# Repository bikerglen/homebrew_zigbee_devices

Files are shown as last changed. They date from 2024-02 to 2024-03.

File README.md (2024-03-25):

# homebrew_zigbee_devices

First up: nRF52840-based four-input sleepy end device

Second up: nRF52840-based hall effect contact sensor sleepy end device

1. Install nRF plugins for Visual Studio Code
2. Use the plugin to install version 2.5.1 of the toolchain and sdk
3. Add custom board definition files
4. Add the zigbee_switch_v2 and zigbee_contact_v1 directories as applications.
5. For each application, create a build using the corresponding custom board.
6. Build and flash each application's build.
7. Install four-input.js as a custom handler in zigbee2mqtt.

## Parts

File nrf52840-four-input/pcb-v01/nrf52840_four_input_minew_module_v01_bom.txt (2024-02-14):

C1       Capacitor 0603 0.1uF
C2       Capacitor 1210 100uF
CR2450   TE/Linx BAT-HLD-008-SMT
D1       LED 0805
D7       LED 0805
J1       Samtec FTS-105-01-F-DV-P-TRJ
J2       Phoenix 1725685
R1       Resistor 0603 10k
R2       Resistor 0603 1k
R3       Resistor 0603 1k
SW1      Button KMR211NGLFS
SW2      Button KMR211NGLFS
U1       Wireless Module

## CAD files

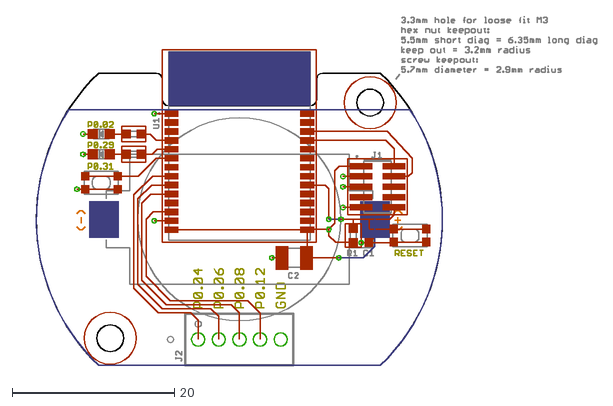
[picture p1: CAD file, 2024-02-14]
nrf52840-four-input/pcb-v01/nrf52840_four_input_minew_module_v01.dxf
71.5 x 43.0

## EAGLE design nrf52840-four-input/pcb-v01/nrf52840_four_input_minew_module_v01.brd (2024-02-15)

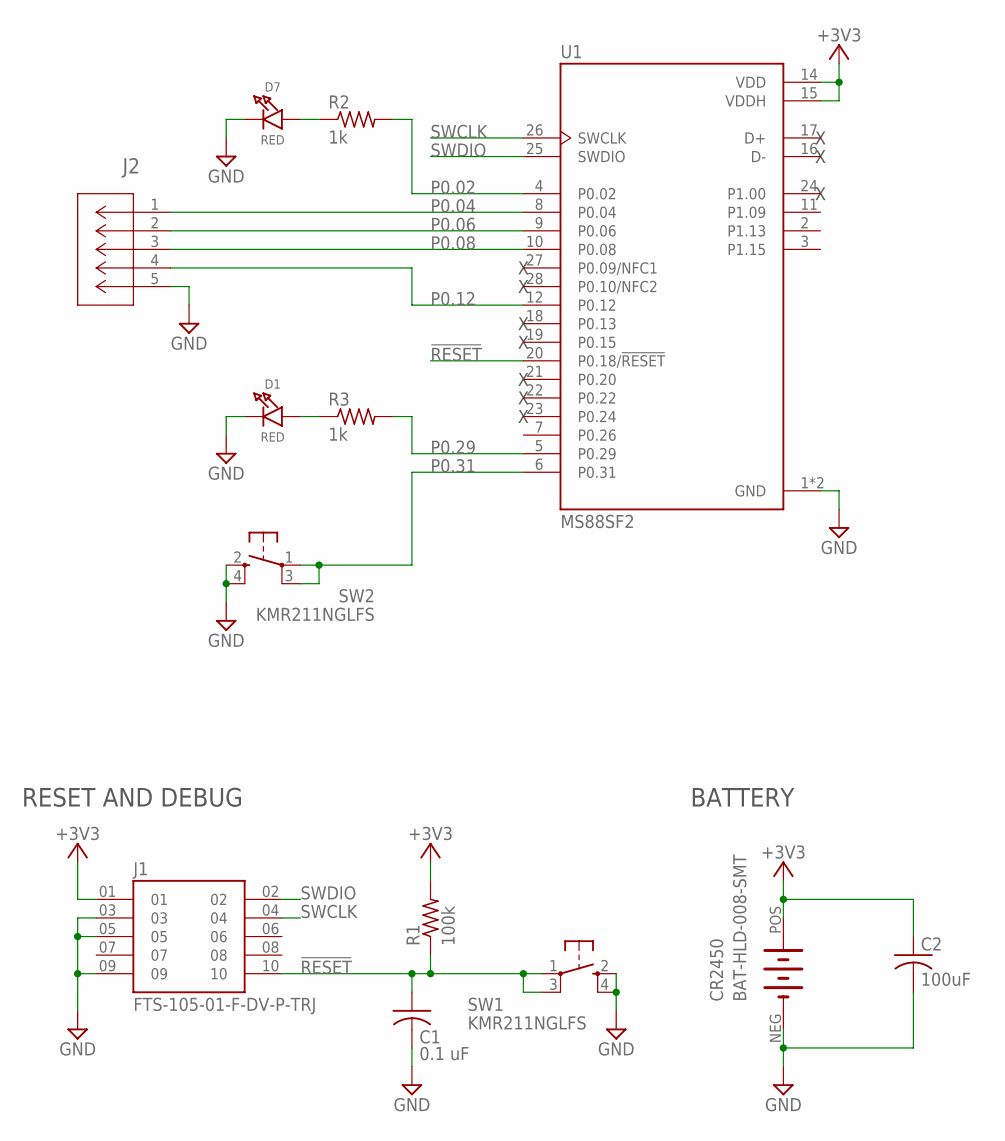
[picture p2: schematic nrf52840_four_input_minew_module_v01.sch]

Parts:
C1: 0.1 uF; C0603K
C2: 100uF; C1210K
CR2450: BAT-HLD-008-SMT
D1, D7: RED; CHIPLED_0805_NOOUTLINE
J1: FTS-105-01-F-DV-P-TRJ; SAMTEC_FTS-105-01-F-DV-P-TR
J2: 1725685; CONN_1725685_PXC
R1: 100k; R0603
R2, R3: 1k; R0603
SW1, SW2: KMR211NGLFS; KMR2
U1: MS88SF2; XCVR_MS88SF2

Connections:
!RESET: C1.1, J1.10, R1.1, SW1.1, SW1.3 (P1), U1.20 (P0.18/!RESET)
+3V3: C2.1, CR2450.POS (+), J1.01, R1.2, U1.14 (VDD), U1.15 (VDDH)
GND: C1.2, C2.2, CR2450.NEG (-), D1.C, D7.C, J1.03, J1.05, J1.09, J2.5, SW1.2 (S), SW1.4 (S1), SW2.2 (S), SW2.4 (S1), U1.1 (GND), U1.13 (GND)
unnamed: D7.A, R2.1
unnamed: D1.A, R3.1
P0.02: R2.2, U1.4 (P0.02)
P0.04: J2.1, U1.8 (P0.04)
P0.06: J2.2, U1.9 (P0.06)
P0.08: J2.3, U1.10 (P0.08)
P0.12: J2.4, U1.12 (P0.12)
P0.29: R3.2, U1.5 (P0.29)
P0.31: SW2.1, SW2.3 (P1), U1.6 (P0.31)
SWCLK: J1.04, U1.26 (SWCLK)
SWDIO: J1.02, U1.25 (SWDIO)

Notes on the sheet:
RESET AND DEBUG
BATTERY

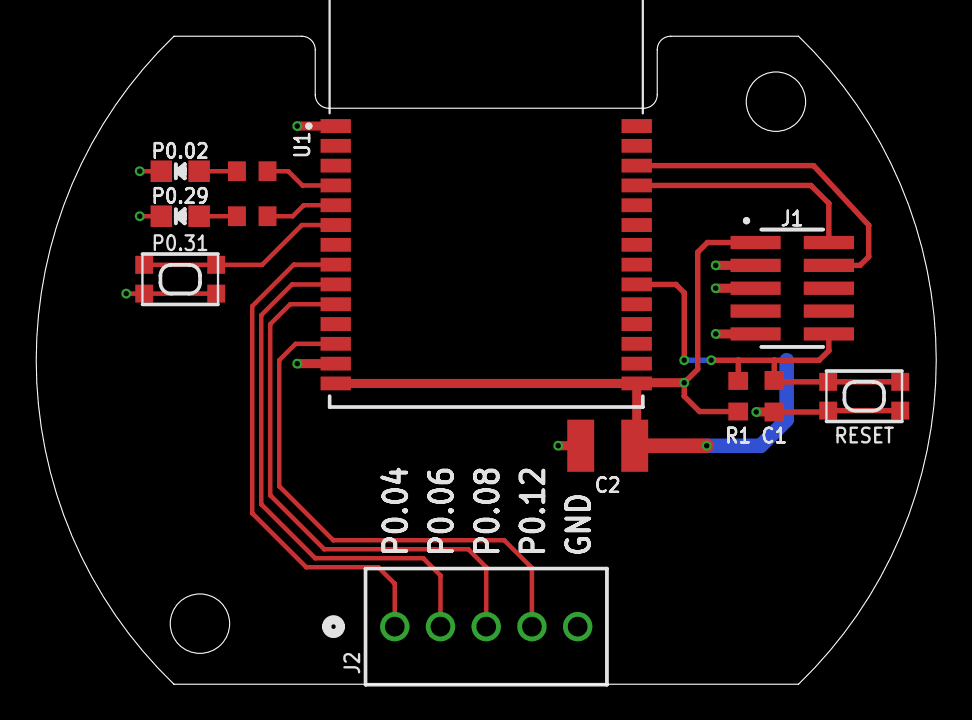
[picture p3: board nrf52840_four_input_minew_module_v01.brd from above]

Board: 2 copper layers, 50.0 x 36.0 mm, 13 parts (1 on the bottom side), 14 nets.

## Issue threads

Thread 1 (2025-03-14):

Power consumption after clic

rdorys, 2025-03-14:
Hi @bikerglen,

First off, thank you for this amazing repository! It has been incredibly helpful in building a Zigbee button based on the nRF52840. Everything is working quite well, but there’s one thing I’m struggling to understand.

I’m using a 52840 DK and measuring around 2.8uA when the system is idle (which is fine, although I’m curious how you’re achieving the 1.8uA consumption).

The issue I’m facing is that after pressing the button, a 3-minute network activity window starts, with a periodic signal every 3 seconds.

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

I’m unable to figure out what’s happening or what the chip is doing during this time. I’ve tried adjusting polling values, disabling turbo poll, and changing the rejoin timeout, but nothing seems to work.

What’s odd is that this behavior doesn’t occur with every button press. If I press the button a bit longer (about 0.3s), there's a high chance that the current drops back down to 2.8uA right after releasing the button.

Do you have any insights on this? Have you observed this behavior in your final product? The only change I made to your code was adjusting the four-button setup to match the DK pinout.

I’m using the nRF SDK 2.8.0.

Thanks again, and looking forward to your thoughts!

Best regards

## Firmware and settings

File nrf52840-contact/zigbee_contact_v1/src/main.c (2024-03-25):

//---------------------------------------------------------------------------------------------
// includes
//

#include <zephyr/kernel.h>
#include <zephyr/device.h>
#include <zephyr/logging/log.h>
#include <zephyr/drivers/gpio.h>
#include <ram_pwrdn.h>

#include <drivers/include/nrfx_saadc.h>

#include <zboss_api.h>
#include <zboss_api_addons.h>
#include <zb_zcl_reporting.h>
#include <zigbee/zigbee_app_utils.h>
#include <zigbee/zigbee_error_handler.h>
#include <zb_nrf_platform.h>
#include "zb_mem_config_custom.h"
#include "zb_four_input.h"

#include "leds.h"
#include "buttons.h"


//---------------------------------------------------------------------------------------------
// defines
//

// Basic cluster attributes initial values. For more information, see section 3.2.2.2 of the ZCL specification.
#define FOUR_INPUT_INIT_BASIC_APP_VERSION       01                                  // Version of the application software (1 byte).
#define FOUR_INPUT_INIT_BASIC_STACK_VERSION     10                                  // Version of the implementation of the Zigbee stack (1 byte).
#define FOUR_INPUT_INIT_BASIC_HW_VERSION        11                                  // Version of the hardware of the device (1 byte).
#define FOUR_INPUT_INIT_BASIC_MANUF_NAME        "bikerglen.com"                     // Manufacturer name (32 bytes).
#define FOUR_INPUT_INIT_BASIC_MODEL_ID          "four-input"                        // Model number assigned by the manufacturer (32-bytes long string).
#define FOUR_INPUT_INIT_BASIC_DATE_CODE         "20240226"                          // Date provided by the manufacturer of the device in ISO 8601 format (YYYYMMDD), for the first 8 bytes. The remaining 8 bytes are manufacturer-specific.
#define FOUR_INPUT_INIT_BASIC_POWER_SOURCE      ZB_ZCL_BASIC_POWER_SOURCE_BATTERY   // Type of power source or sources available for the device. For possible values, see section 3.2.2.2.8 of the ZCL specification.
#define FOUR_INPUT_INIT_BASIC_LOCATION_DESC     "Earth"                             // Description of the physical location of the device (16 bytes). You can modify it during the commisioning process.
#define FOUR_INPUT_INIT_BASIC_PH_ENV            ZB_ZCL_BASIC_ENV_UNSPECIFIED        // Description of the type of physical environment. For possible values, see section 3.2.2.2.10 of the ZCL specification.

// source endpoint for our device
#define SOURCE_ENDPOINT            1

// destination short address and endpoint (always endpoint 1 on the coordinator)
#define DEST_SHORT_ADDR            0x0000
#define DEST_ENDPOINT              1

// Do not erase NVRAM to save the network parameters after device reboot or
// power-off. NOTE: If this option is set to ZB_TRUE then do full device erase
// for all network devices before running other samples.
#define ERASE_PERSISTENT_CONFIG    ZB_FALSE

// LEDs
#define ZIGBEE_NETWORK_STATE_LED   0      // on: disconnected, blinking: identify, off: normal operation
#define USER_LED                   1      // unused

// Buttons
#define BUTTON_0                   BIT(0) // send zcl off/on/toggle/custom commands
#define BUTTON_1                   BIT(1) // short press: identify, long press: factory reset

// no idea but required for successful compile
#define bat_num

// read and report battery voltage after an initial delay after joining the network 
// then read and report battery voltage after the specified period elapses.
#define READ_BATTERY_VOLTAGE_INITIAL_DELAY K_SECONDS(10)
#define READ_BATTERY_VOLTAGE_TIMER_PERIOD  K_HOURS(8)


//---------------------------------------------------------------------------------------------
// typedefs
//

// attribute storage for battery power config
struct zb_zcl_power_attrs {
    zb_uint8_t voltage; // Attribute 3.3.2.2.3.1
    zb_uint8_t size; // Attribute 3.3.2.2.4.2
    zb_uint8_t quantity; // Attribute 3.3.2.2.4.4
    zb_uint8_t rated_voltage; // Attribute 3.3.2.2.4.5
    zb_uint8_t alarm_mask; // Attribute 3.3.2.2.4.6
    zb_uint8_t voltage_min_threshold; // Attribute 3.3.2.2.4.7
    zb_uint8_t percent_remaining; // Attribute 3.3.2.2.3.1
    zb_uint8_t voltage_threshold_1; // Attribute 3.3.2.2.4.8
    zb_uint8_t voltage_threshold_2; // Attribute 3.3.2.2.4.8
    zb_uint8_t voltage_threshold_3; // Attribute 3.3.2.2.4.8
    zb_uint8_t percent_min_threshold; // Attribute 3.3.2.2.4.9
    zb_uint8_t percent_threshold_1; // Attribute 3.3.2.2.4.10
    zb_uint8_t percent_threshold_2; // Attribute 3.3.2.2.4.10
    zb_uint8_t percent_threshold_3; // Attribute 3.3.2.2.4.10
    zb_uint32_t alarm_state; // Attribute 3.3.2.2.4.11
};

typedef struct zb_zcl_power_attrs zb_zcl_power_attrs_t;

// attribute storage for our device
struct zb_device_ctx {
	zb_zcl_basic_attrs_ext_t basic_attr;
	zb_zcl_identify_attrs_t identify_attr;
	zb_zcl_power_attrs_t power_attr;
};

// storage for the destination short address and endpoint number
struct dest_context {
	zb_uint8_t endpoint;
	zb_uint16_t short_addr;
};

// coin cell voltage-capacity pairs
typedef struct {
  uint16_t      voltage;
  uint8_t       capacity;
} voltage_capacity_pair_t;


//---------------------------------------------------------------------------------------------
// Prototypes
//

// used to display reporting info structures if needed
zb_zcl_reporting_info_t *zb_zcl_get_reporting_info(zb_uint8_t slot_number);

void zboss_signal_handler (zb_bufid_t bufid);
static void configure_gpio (void);
static void button_handler (uint32_t button_state, uint32_t has_changed);
static void light_switch_send_on_off (zb_bufid_t bufid, zb_uint16_t cmd_id);
static void start_identifying (zb_bufid_t bufid);
static void identify_cb (zb_bufid_t bufid);
static void toggle_identify_led (zb_bufid_t bufid);
static void app_clusters_attr_init (void);
static void configure_attribute_reporting (void);
static void read_battery_voltage_cb (struct k_timer *timer);
static void read_battery_voltage_work_handler(struct k_work *work);
static uint8_t cr2032_CalculateLevel (uint16_t voltage);
static void send_attribute_report (zb_bufid_t bufid, zb_uint16_t cmd_id);

#if DT_NODE_EXISTS(DT_NODELABEL(sw_spi_cs_n))
static void power_down_spi_flash (void);
#endif


//---------------------------------------------------------------------------------------------
// Globals
//

#if !defined ZB_ED_ROLE
#error Define ZB_ED_ROLE to compile light switch (End Device) source code.
#endif

LOG_MODULE_REGISTER (app, LOG_LEVEL_INF);

// attribute storage for our device
static struct zb_device_ctx dev_ctx;

// storage for the destination short address and endpoint number
static struct dest_context dest_ctx;

// Declare attribute list for Basic cluster (server).
ZB_ZCL_DECLARE_BASIC_ATTRIB_LIST_EXT
(
	basic_server_attr_list,
	&dev_ctx.basic_attr.zcl_version,
	&dev_ctx.basic_attr.app_version,
	&dev_ctx.basic_attr.stack_version,
	&dev_ctx.basic_attr.hw_version,
	dev_ctx.basic_attr.mf_name,
	dev_ctx.basic_attr.model_id,
	dev_ctx.basic_attr.date_code,
	&dev_ctx.basic_attr.power_source,
	dev_ctx.basic_attr.location_id,
	&dev_ctx.basic_attr.ph_env,
	dev_ctx.basic_attr.sw_ver
);

// Declare attribute list for Identify cluster (client).
ZB_ZCL_DECLARE_IDENTIFY_CLIENT_ATTRIB_LIST
(
	identify_client_attr_list
);

// Declare attribute list for Identify cluster (server).
ZB_ZCL_DECLARE_IDENTIFY_SERVER_ATTRIB_LIST
(
	identify_server_attr_list,
	&dev_ctx.identify_attr.identify_time
);

// Declare attribute list for On/Off cluster (client).
ZB_ZCL_DECLARE_ON_OFF_CLIENT_ATTRIB_LIST
(
	on_off_client_attr_list
);

// Declare attribute list for power configuration cluster (server).
ZB_ZCL_DECLARE_POWER_CONFIG_BATTERY_ATTRIB_LIST_EXT(
	power_config_server_attr_list,
	&dev_ctx.power_attr.voltage,
	&dev_ctx.power_attr.size,
	&dev_ctx.power_attr.quantity,
	&dev_ctx.power_attr.rated_voltage,
	&dev_ctx.power_attr.alarm_mask,
	&dev_ctx.power_attr.voltage_min_threshold,
	&dev_ctx.power_attr.percent_remaining,
	&dev_ctx.power_attr.voltage_threshold_1,
	&dev_ctx.power_attr.voltage_threshold_2,
	&dev_ctx.power_attr.voltage_threshold_3,
	&dev_ctx.power_attr.percent_min_threshold,
	&dev_ctx.power_attr.percent_threshold_1,
	&dev_ctx.power_attr.percent_threshold_2,
	&dev_ctx.power_attr.percent_threshold_3,
	&dev_ctx.power_attr.alarm_state
);

// Declare cluster list for four input device.
ZB_DECLARE_FOUR_INPUT_CLUSTER_LIST
(
	four_input_clusters,
	basic_server_attr_list,
	identify_client_attr_list,
	identify_server_attr_list,
	on_off_client_attr_list,
	power_config_server_attr_list
);

// Declare endpoint for four input device.
ZB_DECLARE_FOUR_INPUT_EP
(
	four_input_ep,
	SOURCE_ENDPOINT,
	four_input_clusters
);

// Declare application's device context (list of registered endpoints) for four input device.
ZBOSS_DECLARE_DEVICE_CTX_1_EP
(
	four_input_ctx, 
	four_input_ep
);

// alarm for taking an ADC reading every 6 hours
struct k_timer read_battery_voltage_timer;
K_WORK_DEFINE (read_battery_voltage_work, read_battery_voltage_work_handler);

// Voltage - Capacity pair table from thunderboard react
// Algorithm assumes the values are arranged in a descending order.
// The values in the table are an average of those found in the CR2032 datasheets from
// Energizer, Maxell and Panasonic. Table modified for zigbee half percent steps.
static voltage_capacity_pair_t vcPairs[] =
{ { 3000, 200 }, { 2900, 160 }, { 2800, 120 }, { 2700, 80 }, { 2600, 60 },
  { 2500, 40 }, { 2400, 20 }, { 2000, 0 } };


//---------------------------------------------------------------------------------------------
// main
//

int main (void)
{
	LOG_INF ("Starting Four Input Device");

	// initialize
	configure_gpio ();
	register_factory_reset_button (BUTTON_1);
	zigbee_erase_persistent_storage (ERASE_PERSISTENT_CONFIG);
	zb_set_ed_timeout (ED_AGING_TIMEOUT_64MIN);
    zb_set_keepalive_timeout (ZB_MILLISECONDS_TO_BEACON_INTERVAL(3600*1000));
    
#if DT_NODE_EXISTS (DT_NODELABEL (sw_spi_cs_n))
	// place spi flash in power down mode
	power_down_spi_flash ();
#endif

	// send things to endpoint 1 on the coordinator
	dest_ctx.short_addr = DEST_SHORT_ADDR;
	dest_ctx.endpoint = DEST_ENDPOINT;

	// configure for lowest power
	zigbee_configure_sleepy_behavior (true);
	power_down_unused_ram ();

	// register switch device context (endpoints)
	ZB_AF_REGISTER_DEVICE_CTX (&four_input_ctx);

	// initialize application clusters
	app_clusters_attr_init ();

	// register handlers to identify notifications
	ZB_AF_SET_IDENTIFY_NOTIFICATION_HANDLER(SOURCE_ENDPOINT, identify_cb);

	// initialize read battery voltage timer
	k_timer_init (&read_battery_voltage_timer, read_battery_voltage_cb, NULL);

	// start Zigbee default thread
	zigbee_enable ();

	LOG_INF ("Four Input Device started");

	// suspend main thread
	while (1) {
		k_sleep (K_FOREVER);
	}
}


//---------------------------------------------------------------------------------------------
// zigbee stack event handler
//

void zboss_signal_handler(zb_bufid_t bufid)
{
	static bool lastJoin = false;

	zb_zdo_app_signal_hdr_t *sig_hndler = NULL;
	zb_zdo_app_signal_type_t sig = zb_get_app_signal(bufid, &sig_hndler);
	zb_ret_t status = ZB_GET_APP_SIGNAL_STATUS(bufid);

	// Update network status LED.
	// zigbee_led_status_update(bufid, ZIGBEE_NETWORK_STATE_LED);

	// Call default signal handler until there's a reason to check for different signals
	// the default handler evens calls zb_sleep_now for us
	ZB_ERROR_CHECK(zigbee_default_signal_handler(bufid));

	// free buffer if it's allocated
	if (bufid) {
		zb_buf_free(bufid);
	}

	// once joined, set the poll and battery voltage intervals to an hour.
	// if using a sparkfun board with a spi flash chip, drop the flash chip 
	// into power down mode again just in case missed it the first time.
	bool thisJoin = ZB_JOINED();
	if ((lastJoin == false) && (thisJoin == true)) {
		LOG_INF ("joined network!");
		led_set_off (ZIGBEE_NETWORK_STATE_LED);
		zb_zdo_pim_set_long_poll_interval (3600*1000);
		configure_attribute_reporting ();
		status = zb_zcl_start_attr_reporting(SOURCE_ENDPOINT, ZB_ZCL_CLUSTER_ID_POWER_CONFIG, ZB_ZCL_CLUSTER_SERVER_ROLE, ZB_ZCL_ATTR_POWER_CONFIG_BATTERY_VOLTAGE_ID);
		k_timer_start(&read_battery_voltage_timer, READ_BATTERY_VOLTAGE_INITIAL_DELAY, READ_BATTERY_VOLTAGE_TIMER_PERIOD);
#if DT_NODE_EXISTS(DT_NODELABEL(sw_spi_cs_n))
		power_down_spi_flash ();
#endif
	} else if ((lastJoin == true) && (thisJoin == false)) {
		LOG_INF ("left network!");
		// no longer joined, turn on network state led and stop reading battery voltage
		led_set_on (ZIGBEE_NETWORK_STATE_LED);
		k_timer_stop(&read_battery_voltage_timer);
	}
	lastJoin = thisJoin;
}


//---------------------------------------------------------------------------------------------
// configure attribute reporting
//

#define RPT_MIN 0x0001
#define RPT_MAX 0xFFFE

static void configure_attribute_reporting (void)
{
	// If the maximum reporting interval is set to 0xffff then the device shall not issue any 
	// reports for the attribute. If it is set to 0x0000 and minimum reporting interval is set 
	// to something other than 0xffff then the device shall not do periodic reporting.
	// It can still send reports on value change in the last case, but not periodic.

	zb_zcl_reporting_info_t batt_rep_info;
	zb_ret_t status;

	memset(&batt_rep_info, 0, sizeof(batt_rep_info));
	batt_rep_info.direction = ZB_ZCL_CONFIGURE_REPORTING_SEND_REPORT;
	batt_rep_info.ep = SOURCE_ENDPOINT;
	batt_rep_info.cluster_id = ZB_ZCL_CLUSTER_ID_POWER_CONFIG;
	batt_rep_info.cluster_role = ZB_ZCL_CLUSTER_SERVER_ROLE;
	batt_rep_info.attr_id = ZB_ZCL_ATTR_POWER_CONFIG_BATTERY_VOLTAGE_ID;
	batt_rep_info.dst.short_addr = 0x0000;
	batt_rep_info.dst.endpoint = 1;
	batt_rep_info.dst.profile_id = ZB_AF_HA_PROFILE_ID;
	batt_rep_info.u.send_info.min_interval = RPT_MIN;
	batt_rep_info.u.send_info.max_interval = 0;
	batt_rep_info.u.send_info.delta.u8 = 0x00;
	batt_rep_info.u.send_info.reported_value.u8 = 0;
	batt_rep_info.u.send_info.def_min_interval = RPT_MIN;
	batt_rep_info.u.send_info.def_max_interval = RPT_MAX;
	status = zb_zcl_put_reporting_info(&batt_rep_info, ZB_TRUE);       

	memset(&batt_rep_info, 0, sizeof(batt_rep_info));
	batt_rep_info.direction = ZB_ZCL_CONFIGURE_REPORTING_SEND_REPORT;
	batt_rep_info.ep = SOURCE_ENDPOINT;
	batt_rep_info.cluster_id = ZB_ZCL_CLUSTER_ID_POWER_CONFIG;
	batt_rep_info.cluster_role = ZB_ZCL_CLUSTER_SERVER_ROLE;
	batt_rep_info.attr_id = ZB_ZCL_ATTR_POWER_CONFIG_BATTERY_PERCENTAGE_REMAINING_ID;
	batt_rep_info.dst.short_addr = 0x0000;
	batt_rep_info.dst.endpoint = 1;
	batt_rep_info.dst.profile_id = ZB_AF_HA_PROFILE_ID;
	batt_rep_info.u.send_info.min_interval = RPT_MIN;
	batt_rep_info.u.send_info.max_interval = RPT_MAX;
	batt_rep_info.u.send_info.delta.u8 = 0x00;
	batt_rep_info.u.send_info.reported_value.u8 = 0;
	batt_rep_info.u.send_info.def_min_interval = RPT_MIN;
	batt_rep_info.u.send_info.def_max_interval = RPT_MAX;
	status = zb_zcl_put_reporting_info(&batt_rep_info, ZB_TRUE);       

	memset(&batt_rep_info, 0, sizeof(batt_rep_info));
	batt_rep_info.direction = ZB_ZCL_CONFIGURE_REPORTING_SEND_REPORT;
	batt_rep_info.ep = SOURCE_ENDPOINT;
	batt_rep_info.cluster_id = ZB_ZCL_CLUSTER_ID_POWER_CONFIG;
	batt_rep_info.cluster_role = ZB_ZCL_CLUSTER_SERVER_ROLE;
	batt_rep_info.attr_id = ZB_ZCL_ATTR_POWER_CONFIG_BATTERY_ALARM_STATE_ID;
	batt_rep_info.dst.short_addr = 0x0000;
	batt_rep_info.dst.endpoint = 1;
	batt_rep_info.dst.profile_id = ZB_AF_HA_PROFILE_ID;
	batt_rep_info.u.send_info.min_interval = RPT_MIN;
	batt_rep_info.u.send_info.max_interval = RPT_MAX;
	batt_rep_info.u.send_info.delta.u8 = 0x00;
	batt_rep_info.u.send_info.reported_value.u32 = 0;
	batt_rep_info.u.send_info.def_min_interval = RPT_MIN;
	batt_rep_info.u.send_info.def_max_interval = RPT_MAX;
	status = zb_zcl_put_reporting_info(&batt_rep_info, ZB_TRUE);       
}


//---------------------------------------------------------------------------------------------
// configure LEDs and buttons
//

static void configure_gpio (void)
{
	int err;

	led_init ();

#if DT_NODE_EXISTS(DT_NODELABEL(led0))
	// turn led on until network is joined
	led_set_on (ZIGBEE_NETWORK_STATE_LED); 
#endif

#if DT_NODE_EXISTS(DT_NODELABEL(led1))
	// turn unused user LED off
	led_set_off (USER_LED); 
#endif

	buttons_init (button_handler);
}


//---------------------------------------------------------------------------------------------
// set default values of attributes in the application's clusters
//

static void app_clusters_attr_init (void)
{
	// Basic cluster attributes data.
	dev_ctx.basic_attr.zcl_version   = ZB_ZCL_VERSION;
	dev_ctx.basic_attr.power_source  = ZB_ZCL_BASIC_POWER_SOURCE_UNKNOWN;
    dev_ctx.basic_attr.power_source  = FOUR_INPUT_INIT_BASIC_POWER_SOURCE;
    dev_ctx.basic_attr.stack_version = FOUR_INPUT_INIT_BASIC_STACK_VERSION;
    dev_ctx.basic_attr.hw_version    = FOUR_INPUT_INIT_BASIC_HW_VERSION;

    // Use ZB_ZCL_SET_STRING_VAL to set strings, because the first byte should
    // contain string length without trailing zero.
    //
    // For example "test" string wil be encoded as:
    //   [(0x4), 't', 'e', 's', 't']

    ZB_ZCL_SET_STRING_VAL(dev_ctx.basic_attr.mf_name,
                          FOUR_INPUT_INIT_BASIC_MANUF_NAME,
                          ZB_ZCL_STRING_CONST_SIZE(FOUR_INPUT_INIT_BASIC_MANUF_NAME));

    ZB_ZCL_SET_STRING_VAL(dev_ctx.basic_attr.model_id,
                          FOUR_INPUT_INIT_BASIC_MODEL_ID,
                          ZB_ZCL_STRING_CONST_SIZE(FOUR_INPUT_INIT_BASIC_MODEL_ID));

    ZB_ZCL_SET_STRING_VAL(dev_ctx.basic_attr.date_code,
                          FOUR_INPUT_INIT_BASIC_DATE_CODE,
                          ZB_ZCL_STRING_CONST_SIZE(FOUR_INPUT_INIT_BASIC_DATE_CODE));


    ZB_ZCL_SET_STRING_VAL(dev_ctx.basic_attr.location_id,
                          FOUR_INPUT_INIT_BASIC_LOCATION_DESC,
                          ZB_ZCL_STRING_CONST_SIZE(FOUR_INPUT_INIT_BASIC_LOCATION_DESC));


    dev_ctx.basic_attr.ph_env = FOUR_INPUT_INIT_BASIC_PH_ENV;

	// Identify cluster attributes data.
	dev_ctx.identify_attr.identify_time = ZB_ZCL_IDENTIFY_IDENTIFY_TIME_DEFAULT_VALUE;

	// Power config attributes data.
	dev_ctx.power_attr.voltage               = ZB_ZCL_POWER_CONFIG_BATTERY_VOLTAGE_INVALID;
	dev_ctx.power_attr.size                  = ZB_ZCL_POWER_CONFIG_BATTERY_SIZE_OTHER;
	dev_ctx.power_attr.quantity              = 1;
	dev_ctx.power_attr.rated_voltage         = 30;
	dev_ctx.power_attr.alarm_mask            = 0x00;
	dev_ctx.power_attr.voltage_min_threshold = 20;
	dev_ctx.power_attr.percent_remaining     = ZB_ZCL_POWER_CONFIG_BATTERY_REMAINING_UNKNOWN;
	dev_ctx.power_attr.voltage_threshold_1   = 22;
	dev_ctx.power_attr.voltage_threshold_2   = 24;
	dev_ctx.power_attr.voltage_threshold_3   = 26;
	dev_ctx.power_attr.percent_min_threshold = 2*10;
	dev_ctx.power_attr.percent_threshold_1   = 2*15;
	dev_ctx.power_attr.percent_threshold_2   = 2*20;
	dev_ctx.power_attr.percent_threshold_3   = 2*25;
	dev_ctx.power_attr.alarm_state           = 0x00000000;
}


//---------------------------------------------------------------------------------------------
// button event handler
//

static void button_handler (uint32_t button_state, uint32_t has_changed)
{
	zb_uint16_t cmd_id = 0xFFFF;
	zb_ret_t zb_err_code;

	LOG_INF ("button_handler");

	// inform default signal handler about user input at the device
	user_input_indicate ();

    // check for start of factory reset
	check_factory_reset_button (button_state, has_changed);

	// check for button presses and releases
	if (BUTTON_0 & has_changed & button_state) {			// magnet away from sensor => high => on
		cmd_id = ZB_ZCL_CMD_ON_OFF_ON_ID;
	} else if (BUTTON_0 & has_changed & ~button_state) {	// magnet near sensor => low => off
		cmd_id = ZB_ZCL_CMD_ON_OFF_OFF_ID;
	} else if (BUTTON_1 & has_changed & ~button_state) {	// button 1 released
		// button 1 released: if not factory reset, enter identify mode
		if (!was_factory_reset_done ()) {
			// Button released before Factory Reset, Start identification mode
			ZB_SCHEDULE_APP_CALLBACK (start_identifying, 0);
		}
	}

	// if needed, send a command
	if (cmd_id != 0xFFFF) {
		zb_err_code = zb_buf_get_out_delayed_ext (light_switch_send_on_off, cmd_id, 0);
		ZB_ERROR_CHECK (zb_err_code);
	}

	// led_set_on (USER_LED); 
	// led_set_off (USER_LED); 
}


//---------------------------------------------------------------------------------------------
// send light switch on off command
//
// bufid    Non-zero reference to Zigbee stack buffer that will be used to construct on/off request.
// cmd_id   ZCL command id.
//

static void light_switch_send_on_off (zb_bufid_t bufid, zb_uint16_t cmd_id)
{
	LOG_INF("Send ON/OFF command: %d", cmd_id);

	ZB_ZCL_ON_OFF_SEND_REQ(bufid,
			       dest_ctx.short_addr,
			       ZB_APS_ADDR_MODE_16_ENDP_PRESENT,
			       dest_ctx.endpoint,
			       SOURCE_ENDPOINT,
			       ZB_AF_HA_PROFILE_ID,
			       ZB_ZCL_DISABLE_DEFAULT_RESPONSE,
			       cmd_id,
			       NULL);
}


//---------------------------------------------------------------------------------------------
// start identifying
//

static void start_identifying (zb_bufid_t bufid)
{
	ZVUNUSED(bufid);

	if (ZB_JOINED()) {
		// Check if endpoint is in identifying mode,
		// if not, put desired endpoint in identifying mode.
		if (dev_ctx.identify_attr.identify_time ==
		    ZB_ZCL_IDENTIFY_IDENTIFY_TIME_DEFAULT_VALUE) {

			zb_ret_t zb_err_code = zb_bdb_finding_binding_target(SOURCE_ENDPOINT);

			if (zb_err_code == RET_OK) {
				LOG_INF("Enter identify mode");
			} else if (zb_err_code == RET_INVALID_STATE) {
				LOG_WRN("RET_INVALID_STATE - Cannot enter identify mode");
			} else {
				ZB_ERROR_CHECK(zb_err_code);
			}
		} else {
			LOG_INF("Cancel identify mode");
			zb_bdb_finding_binding_target_cancel();
		}
	} else {
		LOG_WRN("Device not in a network - cannot enter identify mode");
	}
}


//---------------------------------------------------------------------------------------------
// identify callback
//
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

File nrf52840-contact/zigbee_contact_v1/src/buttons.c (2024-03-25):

#include <zephyr/kernel.h>
#include <zephyr/device.h>
#include <zephyr/devicetree.h>
#include <zephyr/drivers/gpio.h>

#include "buttons.h"

#define BUTTONS_NODE DT_PATH(buttons)

#define GPIO_SPEC_AND_COMMA(button_or_led) GPIO_DT_SPEC_GET(button_or_led, gpios),

static const struct gpio_dt_spec buttons[] = {
#if DT_NODE_EXISTS(BUTTONS_NODE)
	DT_FOREACH_CHILD(BUTTONS_NODE, GPIO_SPEC_AND_COMMA)
#endif
};

static uint32_t buttons_read (void);
static void buttons_changed (const struct device *gpio_dev, struct gpio_callback *cb, uint32_t pins);

static button_handler_t button_handler_cb;
static struct gpio_callback gpio_cb;
static atomic_t buttons_state;

void buttons_init (button_handler_t button_handler)
{
    int err;

    printk (">>> buttons init\n");

    button_handler_cb = button_handler;

    uint32_t pin_mask = 0;

    for (size_t i = 0; i < ARRAY_SIZE(buttons); i++) {
        printk ("initializing button %d\n", i);

        err = gpio_pin_configure_dt(&buttons[i], GPIO_INPUT);
        if (err) {
			printk ("Cannot configure button gpio");
			return err;
		}

		err = gpio_pin_interrupt_configure_dt(&buttons[i], GPIO_INT_TRIG_BOTH);
        if (err) {
			printk ("Cannot enable trig both callback");
			return err;
		}

		pin_mask |= BIT(buttons[i].pin);
	}

    printk ("pin_mask: %08x\n", pin_mask);

	gpio_init_callback (&gpio_cb, buttons_changed, pin_mask);

	for (size_t i = 0; i < ARRAY_SIZE(buttons); i++) {
		gpio_add_callback (buttons[i].port, &gpio_cb);
	}

	atomic_set (&buttons_state, (atomic_val_t)buttons_read ());

    dk_read_buttons (NULL, NULL);

    printk ("<<< buttons init\n");
}

static uint32_t buttons_read (void)
{
	uint32_t ret = 0;
	for (size_t i = 0; i < ARRAY_SIZE(buttons); i++) {
		int val;
		val = gpio_pin_get_dt(&buttons[i]);
		if (val) {
			ret |= 1U << i;
		}
	}
	return ret;
}

static void buttons_changed (const struct device *gpio_dev, struct gpio_callback *cb, uint32_t pins)
{
    printk ("button changed state\n");

    uint32_t last_buttons = atomic_get (&buttons_state);
    uint32_t this_buttons = buttons_read ();
    uint32_t changed_buttons = last_buttons ^ this_buttons;
 	atomic_set (&buttons_state, (atomic_val_t)this_buttons);

    printk ("buttons changed: last: %08x this: %08x changed: %08x\n", last_buttons, this_buttons, changed_buttons);

	button_handler_cb (this_buttons, changed_buttons);
}

void dk_read_buttons (uint32_t *button_state, uint32_t *has_changed)
{
	static uint32_t last_state;
	uint32_t current_state = atomic_get(&buttons_state);

	if (button_state != NULL) {
		*button_state = current_state;
	}

	if (has_changed != NULL) {
		*has_changed = (current_state ^ last_state);
	}

    printk ("dk_read_buttons: last: %08x this: %08x changed: %08x\n", last_state, current_state, *has_changed);

	last_state = current_state;
}

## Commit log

2024-02-14 initial checkin
    [nrf52840_four_input_minew_module_v01.dxf]
2024-02-14 add bom
2024-02-15 add eagle pcb files
    [nrf52840_four_input_minew_module_v01.brd, nrf52840_four_input_minew_module_v01.sch]
2024-03-03 add zigbee2mqtt driver for the four-input module
2024-03-03 add board defintion files for Nordic nRF Connect plugin for Visual Studio Code
2024-03-25 add hall effect contact sensor device tree files
2024-03-25 add hall effect contact sensor pcb design files
    [nrf52840-contact-v03.brd, nrf52840-contact-v03.sch]
2024-03-25 add zigbee2mqtt file for hall effec contact sensor
2024-03-25 move four input sensor board files and flatten directory hierarchy
    [nrf52840_four_input_minew_module_v01.brd, nrf52840_four_input_minew_module_v01.dxf, nrf52840_four_input_minew_module_v01.sch]
2024-03-25 add contact sensor build files

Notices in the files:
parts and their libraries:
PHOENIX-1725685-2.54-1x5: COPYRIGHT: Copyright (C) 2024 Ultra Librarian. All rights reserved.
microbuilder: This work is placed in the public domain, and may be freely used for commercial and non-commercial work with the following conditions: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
